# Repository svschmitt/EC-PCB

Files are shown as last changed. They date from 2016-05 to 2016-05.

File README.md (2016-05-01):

# EC-PCB
Arduino interface for communication with the Entertainment &amp; Comfort serial bus found in some GM vehicles.

The EAGLE subdirectory contains EAGLE CAD files for an interface to be used with an Arduino Pro Mini.

The ECcomm_adapter subdirectory contains the sketch to upload to the Arduino. This code could be used with other Arduino variants.

The ECcomm_adapter Arduino sketch can communicate with a serial terminal application as well as the co-developed ECcomm program for Linux (https://github.com/svschmitt/ECcomm/ ), which provides additional functionality included message decoding and bidirectional communication.

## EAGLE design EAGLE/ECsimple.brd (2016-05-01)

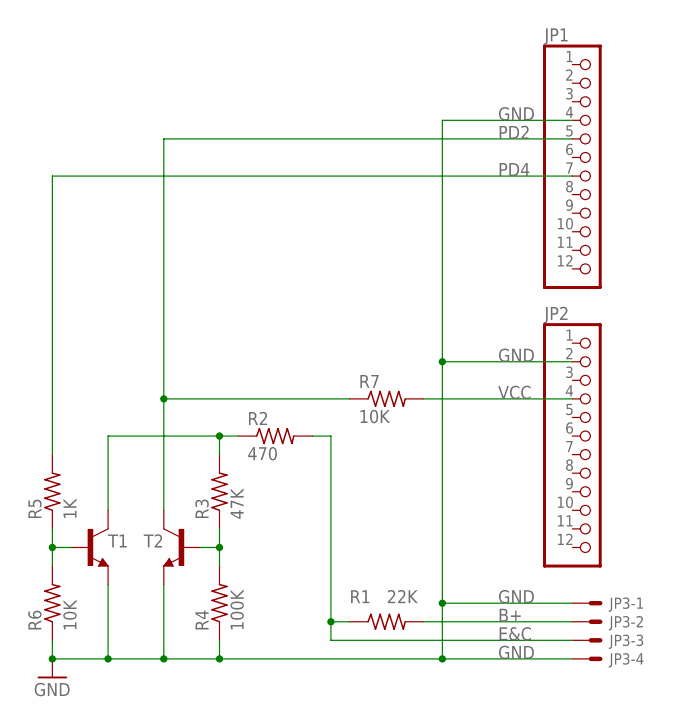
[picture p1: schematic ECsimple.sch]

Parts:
JP1, JP2: PINHD-1X12-CB; 1X12-CB
JP3: HDR_PLAIN_1X4; HDR_1X4
R1: 22K; 0204/7
R2: 470; 0204/7
R3: 47K; 0204/7
R4: 100K; 0204/7
R5: 1K; 0204/7
R6, R7: 10K; 0204/7
T1, T2: NPN-TRANSISTORCLEAN; TO92-NONPOLARIZED-CLEAN

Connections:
B+: JP3.2, R1.2
E&C: JP3.3, R1.1, R2.2
GND: JP1.4, JP2.2, JP3.1, JP3.4, R4.1, R6.1, T1.E, T2.E
unnamed: R2.1, R3.2, T1.C
unnamed: R3.1, R4.2, T2.B
unnamed: R5.1, R6.2, T1.B
PD2: JP1.5, R7.1, T2.C
PD4: JP1.7, R5.2
VCC: JP2.4, R7.2

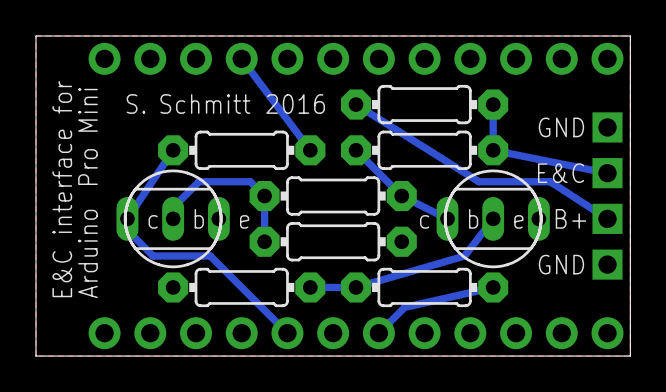
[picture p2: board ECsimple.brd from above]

Board: 2 copper layers, 33.0 x 17.8 mm, 12 parts (0 on the bottom side), 9 nets.

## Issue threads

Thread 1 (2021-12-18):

Worked great from 1994 thru 1999 Delco Radios with the TMS370 microcontroller PCBs

drshock, 2021-12-18:
Thanks for this work, it inspired me to debug how the Theftlock codes are stored and generated in the Texas Instrument TMS370 microcontroller based radios are implemented.   I did a YouTube video on how I utilized your shield and sample code to help analyze communications between the GM Tech2 dealer scan tool and Delco Radios here [Unlock 1990s GM Radio TheftLock Codes with Arduino](https://youtu.be/OJg6czxvJ2I)

I did find that while the E&C bus continued thru 2002 in radios with the same cosmetic appearance, the TMS370 microcontroller was replaced in 2000.  And from that point on the protocol signal timings were changed.   So while I could find 100% repeatable success unlocking 1994 thru 1999 Delco radios, the 2000 thru 2002 ones were unreliable for this same technique as the bus protocols had changed.

It's been some time since I posted the video, but I thought about commenting here in case someone else using this work ran into this same incompatibility with the 2000 thru 2002 versions from Delco Electronics.

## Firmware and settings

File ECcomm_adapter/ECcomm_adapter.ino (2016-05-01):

/* ECcomm_adapter - Microcontroller interface for General Motors
            Entertainment & Comfort serial bus communication.

    Copyright (C) 2016 Stuart V. Schmitt

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
    
    
    This code assumes a 16 MHz AVR with the E&C bus connected through
    inverting transistors to digital pins 3 and 5. Direct port registers
    are used because the overhead associated with Arduino functions
    digitalRead and digitalWrite result in too many lost or damaged
    E&C packets. For more information about the bus or the electrical
    interface, please look at information at
        http://stuartschmitt.com/e_and_c_bus/                      */
        

#include "packet.h"

const byte reg_in = 4;      // Pin 3 register
const byte reg_out = 16;    // Pin 5 register
byte mode = 0;              // 0=ASCII, 1=binary; add 2 if an E&C packet is
                            // being sent from the computer (ESC + 4 bytes)
unsigned long timer = 0;    // Timestamp of last E&C packet received/sent


void setup() {
  Serial.begin(9600);       // No need for faster serial; this is 9.6x E&C
  DDRD |= reg_out;
  DDRD &= ~reg_in;
  PORTD &= ~reg_in;
}


void loop() {
  if (PIND & reg_in) {      // If the bus is active, start a read.
    Packet msg(reg_in, reg_out);
    msg.Read();
    if (msg.Sent()) {       // Here, Sent() filters out some false triggers
      if (mode % 2)
        WriteBinary(msg.Unique(), millis() - timer, msg.Incomplete());
      else
        WriteText(msg.Unique(), millis() - timer, msg.Incomplete());
      timer = millis();
    }
  }
  if (Serial.available() > 0) {
    if (mode > 1) {         // An E&C packet is being sent from the computer
      if (Serial.available() >= 4) { // Don't read until it's fully in buffer
        byte header = Serial.read();
        byte byte1 = Serial.read();
        byte byte2 = Serial.read();
        byte byte3 = Serial.read();
        Packet out(reg_in, reg_out);
        out.Send(header & 3, header >> 2, byte1, byte2, byte3);
        mode -= 2;          // Done reading packet from computer
        if (mode)
          WriteBinary(out.Unique(), millis() - timer, 0);
        else
          WriteText(out.Unique(), millis() - timer, 0);
        timer = millis();
      }
    }
    else {                  // Not in packet read mode
      byte input = Serial.read();
      if (input == 32) {    // Set ASCII display mode
        mode = 0;
        Serial.println("Interface in ASCII mode.");
      }
      else if (input == 0 || input == 2) { // Set binary display mode
        mode = 1;
        Serial.println("Interface in binary mode.");
      }
      else if (input == 27) // Enable packet read mode
        mode += 2;
      // Ignore any other characters!
    }
  }
}


void WriteBinary(unsigned long packet, unsigned long time_gap, byte repaired) {
  // Send an encoded 12-byte sequence to the computer that contains the time
  // since the last E&C packet in milliseconds, the flag for incomplete E&C
  // reception, and the E&C packet contents. The start byte is an ESC, and the
  // subsequent bytes are limited to ASCII 32-95 in order to keep the tty sane
  // regardless of the terminal program. The bytes are packed in a method
  // based on UUencode, which allows six usable bits per byte.
  //   bits 1-32:   time gap between E&C packets
  //   bit 33:      incomplete E&C reception flag
  //   bit 34:      zero
  //   bits 35-66:  the E&C packet
  Serial.write((byte) 27);
  Serial.write(32 + (time_gap & 0x3F));
  Serial.write(32 + ((time_gap & 0xFC0) >> 6));
  Serial.write(32 + ((time_gap & 0x3F000) >> 12));
  Serial.write(32 + ((time_gap & 0xFC0000) >> 18));
  Serial.write(32 + ((time_gap & 0x3F000000) >> 24));
  Serial.write(32 + (((time_gap & 0xC0000000) >> 30) + ((repaired & 3) << 2) + ((packet & 3) << 4)));
  Serial.write(32 + ((packet & 0xFC) >> 2));
  Serial.write(32 + ((packet & 0x3F00) >> 8));
  Serial.write(32 + ((packet & 0xFC000) >> 14));
  Serial.write(32 + ((packet & 0x3F00000) >> 20));
  Serial.write(32 + ((packet & 0xFC000000) >> 26));
}


void WriteText(unsigned long packet, unsigned long time_gap, byte repaired) {
  // Simply print the E&C packet to the serial port. This is convenient when
  // using a simple terminal program to connect to the interface. First, print
  // the time since the last E&C packet in milliseconds. Then print a ":"
  // unless the packet was received incomplete; then print a "#". Then print
  // the E&C packet in PRIORITY-ADDRESS-BYTE1-[BYTE2]-[BYTE3] format.
  Serial.print(time_gap);
  if (repaired)
    Serial.print('#');
  else
    Serial.print(':');
  Serial.print(' ');
  Serial.print(packet & 3);
  Serial.print('-');
  Serial.print((packet & 252) >> 2);
  Serial.print('-');
  Serial.print((packet & 0xFF00) >> 8);
  if (packet > 0xFFFF) {
    Serial.print('-');
    Serial.print((packet & 0xFF0000) >> 16);
  }
  if (packet > 0xFFFFFF) {
    Serial.print('-');
    Serial.print((packet & 0xFF000000) >> 24);
  }
  Serial.println("");
}

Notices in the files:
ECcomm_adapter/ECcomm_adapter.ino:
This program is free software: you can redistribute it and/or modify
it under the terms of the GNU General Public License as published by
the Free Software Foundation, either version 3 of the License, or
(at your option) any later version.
